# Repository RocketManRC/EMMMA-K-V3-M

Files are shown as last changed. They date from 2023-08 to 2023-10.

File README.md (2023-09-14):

# EMMMA-K-V3

# Introduction
The EMMMA-K is a MIDI controller for electronic music that uses touch pins for note keys and user interface. A motion sensor is used to generate MIDI commands for effects such as pitch bend and mod wheel.

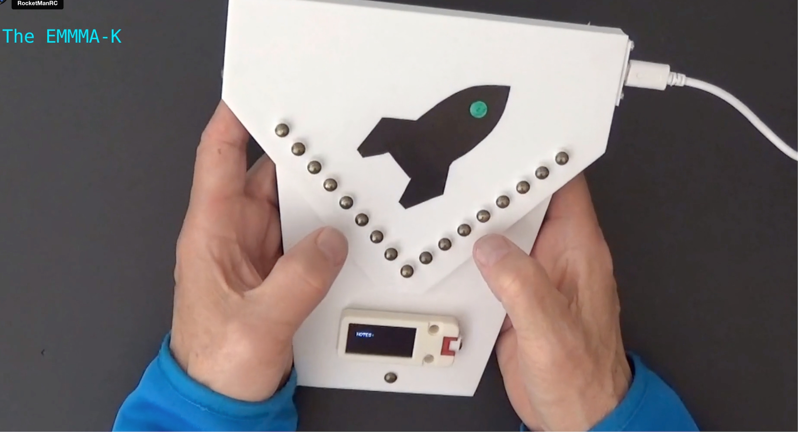
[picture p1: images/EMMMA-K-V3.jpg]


The layout of the touch pins for note keys is modeled after the Kalimba (a.k.a. thumb piano) which is a modernized version of the MBira, an ancient African plucked string instrument.

The history and evolution of the MBira and Kalimba is given on Wikipedia here:

[https://en.wikipedia.org/wiki/Mbira](https://en.wikipedia.org/wiki/Mbira)

A great place to see and hear what the Kalimba is all about is April Yang's YouTube channel:

[https://www.youtube.com/channel/UCV0A2VeScCoxiMhsA2kiIKw](https://www.youtube.com/channel/UCV0A2VeScCoxiMhsA2kiIKw)

In January, 2020 I became interested in making an electronic version of the Kalimba because I wanted a keyboard for electronic music that wasn't piano based and also could be hand-held. In March of that year I started working on a proof-of-concept prototype which I called the EMMMA-K. A write-up of that project is on my website here:

[https://www.rocketmanrc.com/emmma-k.html](https://www.rocketmanrc.com/emmma-k.html)

As crude as that first prototype was it actually performed pretty well and so when the COVID-19 lockdown started I decided to spend the time on a second version that had a better shape and layout and would be easier to build. There is also a write-up of that project here:

[https://www.rocketmanrc.com/emmma-k-v2.html](https://www.rocketmanrc.com/emmma-k-v2.html)

This version supported additional music scales in addition to the Kalimba's C Major scale and a user interface was provided to change scale, key and octave.

Fast forward to October 2022... After working on a number of other unrelated projects I started researching what microcontrollers could be used to replace the TeensyLCs I was using that were no longer available due to the dreaded world-wide semiconductor shortage. The primary requirement was touch pin performance meaning good sensitivity and low latency. I discovered that the new ESP32-S2 and ESP32-S3 from Espressif are excellent for this purpose and so the EMMMA-K-V3 was born.

**Videos:**

[https://vimeo.com/858654116](https://vimeo.com/858654116) Introduction

[https://vimeo.com/858421865](https://vimeo.com/858421865) Overview of Features

[https://vimeo.com/858731197](https://vimeo.com/858731197) Under the Hood

# Features

- Kalimba style keyboard with highly responsive and low latency touch pins.
- USB-C connector for USB MIDI and/or power.
- Wireless MIDI over BLE (Bluetooth Low Energy) or ESP-Now wireless to a USB MIDI hub or a Serial MIDI hub.
- ESP-Now wireless is ultra low latency (approximately 1.5 milliseconds).
- Dedicated option touch pin on the right side to enable tilt sensor for pitch bend and mod wheel (or other CC command).
- Multipurpose option touch pin on the left side for switching between major and minor relative scales, changing to chord mode and disabling the adjacent pin and dissonant note filters.
- User interface with OLED display and dedicated touch pins.
- Change Octave, Key and Scale on the fly or display notes as played.
- Settings mode to enable or disable filters, change MIDI channel, set master volume, set CC for mod wheel and choose wireless mode.

# System Design

This is a dual microcontroller master/slave system with a ESP32-S3 used for the master and a ESP32-S2 (or S3) for the slave. Each microcontroller has 14 touch pins and the ESP32-S3 is required for the master to support wireless over BLE (the ESP32-S2 does not). The microcontrollers exchange pin data via a UART connection with the master polling the slave for synchronous communications. The baud rate is set to 2000000 baud to eliminate any noticable latency.

The motion sensor is a breakout board with a MPU-6050 IMU and is connected to the master via I2C. The board provides three absolute angle measurments (roll, pitch and yaw) using the internal processing of the MPU-6050. The roll axis is used for the mod wheel and the pitch axis is used for pitch bend. The yaw axis is not currently used but could be used for some other purpose.

The use of the motion sensor to generate effects is enabled by touching and holding the option pin on the right hand side of the enclosure. This does not require a note to be played which has the advantage of allowing the EMMMA-K to be used for effects along with another MIDI controller. It also has the advantage that the effects will still be applied to a note with sustain even if the noteoff MIDI command has been issued. When the option pin is touched centre angles are calculated for roll and pitch and then the effects are calculated relative to that those. The logic can be changed so that absolute angles are used which works just as well and is a matter of personal preference. Generation of the effects uses a concept from model aviation called "expo". This means that the change in value of the effects are reduced around around the centre position giving a much smoother response overall.

A OLED display of resolution of 128 by 64 pixels is used for the user interface along with three dedicated touch pins. This display is on a seperate I2C port.

Power for the system is provided by a USB connection to a USB power pack or computer USB port.

To minimize point to point wiring PCBs have been designed to carry both the Master and Slave microcontroller boards.

The microcontroller boards are the ESP32-S3-DevKitC-1 and ESP32-S2-DevKitC-1 from Espressif and are available from all the major component suppliers. Alternatively there are versions of the S3 dev board available from AliExpress.

The code for the slave processor (inspite of what Github says in the repository list and pins) is located here:

[https://github.com/RocketManRC/EMMMA-K-V3-S](https://github.com/RocketManRC/EMMMA-K-V3-S)

The code for the wireless hub is located here:

[https://github.com/RocketManRC/EMMMA-K-V3-W](https://github.com/RocketManRC/EMMMA-K-V3-S)



# Building

I've designed a 3D-printed case that has evolved quite a bit since the very first prototype. I've tried to make it as ergonomic as possible in terms of size and balance and spacing between touch pins. The STL files for 3D printing are here [STL](STL-Files).

It is not necessary to have the 3D-printed case to try out this system as something made of foam board from the Dollar store works just fine.

I do recommend getting the printed circuit boards however as it makes the wiring for the touch pins a lot easier and reproducable although hand wiring will work as well. I had my boards made at JLCPCB. 

The KiCAD 6 design files and the gerbers are here [PCBs](KiCAD).

### Wiring:

| Master MCU | Slave MCU |
| --- | --- |
| GND | GND |
| 38 | TX |
| 39 | RX |

| Master MCU | MPU6050 |
| --- | --- |
| GND | GND |
| 41 | SDA |
| 42 | SCL |
| 3.3V | VCC |

| Master MCU | OLED |
| --- | --- |
| GND | GND |
| 5V | 5V |
| 36 | SCL |
| 35 | SDA |

# Firmware

This is a PlatformIO project using the Arduino Framework. It might be possible to build the firmware using the Arduino IDE however this has not been tested as I don't use the Arduino IDE anymore.

Here is a short YouTube video that shows what is required to build and upload a PlatformIO project [https://www.youtube.com/watch?v=nlE2203Q3XI](https://www.youtube.com/watch?v=nlE2203Q3XI).

### Note: 

There is a quirk with the ESP32-S3 microcontroller that when a project uses USB MIDI the microcontroller must be put in bootloader mode before uploading new firmware otherwise there will be an error. This is not the case if USB MIDI is disabled. In platformio.ini you will see a comment telling how to enable and disable USB MIDI.

# User Guide

# User Interface Photos



### Main Menu:

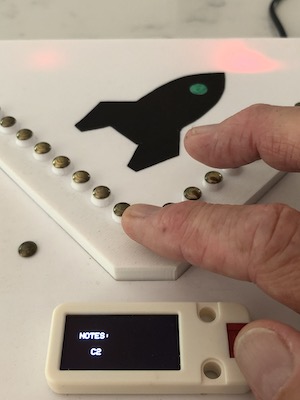
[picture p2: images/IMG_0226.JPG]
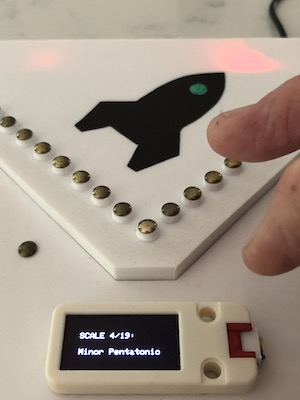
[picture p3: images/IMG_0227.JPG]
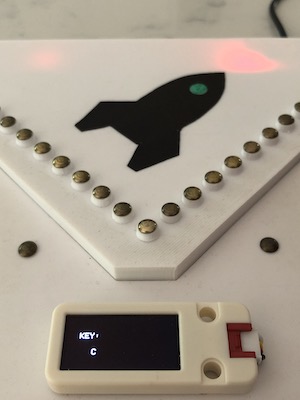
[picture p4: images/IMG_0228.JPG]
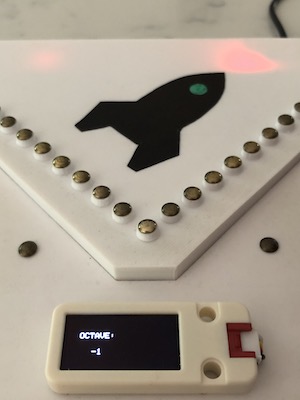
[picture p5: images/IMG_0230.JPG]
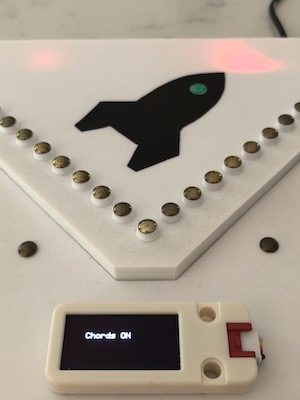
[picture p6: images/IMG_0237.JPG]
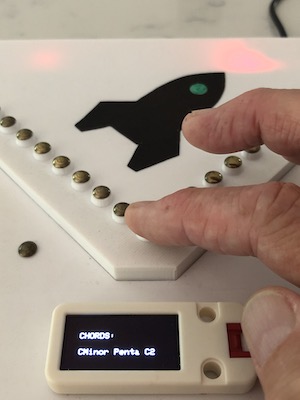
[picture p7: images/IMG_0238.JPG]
      

### Settings:

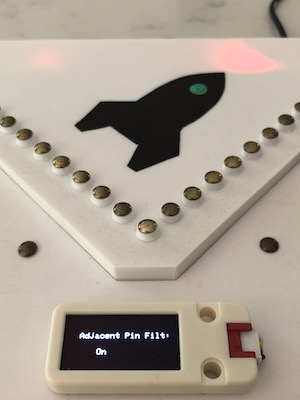
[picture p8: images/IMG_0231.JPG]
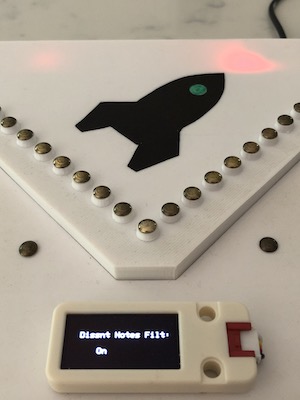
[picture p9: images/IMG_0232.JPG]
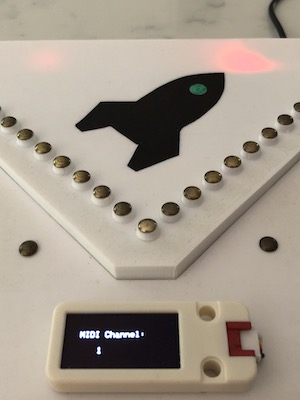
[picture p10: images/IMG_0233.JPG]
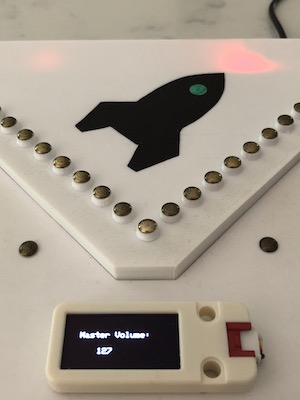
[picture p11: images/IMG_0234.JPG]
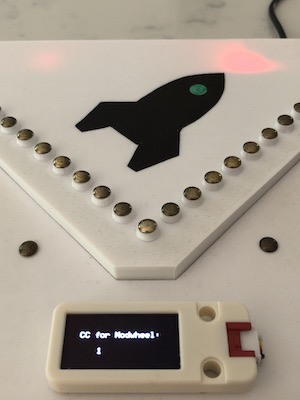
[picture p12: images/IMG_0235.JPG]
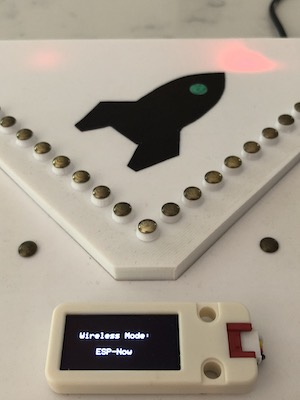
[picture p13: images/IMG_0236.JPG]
     

# Reference Data

ESP32-S2-DevKitC-1: [https://docs.espressif.com/projects/esp-idf/en/latest/esp32s2/hw-reference/esp32s2/user-guide-s2-devkitc-1.html](https://docs.espressif.com/projects/esp-idf/en/latest/esp32s2/hw-reference/esp32s2/user-guide-s2-devkitc-1.html)

ESP32-S3-DevKitC-1: [https://docs.espressif.com/projects/esp-idf/en/latest/esp32s3/hw-reference/esp32s3/user-guide-devkitc-1.html](https://docs.espressif.com/projects/esp-idf/en/latest/esp32s3/hw-reference/esp32s3/user-guide-devkitc-1.html)

ESP32-S3-DevKitC-1 (N8R2 version) from AliExpress: [https://vi.aliexpress.com/item/1005004586894190.html](https://vi.aliexpress.com/item/1005004586894190.html)

USB-C Breakout Board from AliExpress: [https://vi.aliexpress.com/item/1005001337982060.html](https://vi.aliexpress.com/item/1005001337982060.html) Make sure to choose the female connector although having both may come in handy.

Schottky Diode: [https://www.digikey.ca/en/products/detail/panjit-international-inc/SS1040L-R1-00001/14660138](https://www.digikey.ca/en/products/detail/panjit-international-inc/SS1040L-R1-00001/14660138)

Upholstery Nails (for touch pins): [https://www.amazon.ca/Upholstery-Vintage-Furniture-Upholster-Decorative/dp/B08Q7XC9Y1](https://www.amazon.ca/Upholstery-Vintage-Furniture-Upholster-Decorative/dp/B08Q7XC9Y1)

ABS Glue: [https://a.co/d/97ip9cB](https://a.co/d/97ip9cB) I purchased this locally at the hardware store.

Nylon Standoffs and screws: [https://a.co/d/cQluBSF](https://a.co/d/cQluBSF)

M5 Stack OLED Display: [https://vi.aliexpress.com/item/1005003297480376.html](https://vi.aliexpress.com/item/1005003297480376.html) I bought mine from DigiKey for less but at the moment (September 14, 2023) they only have 2 left in stock

MPU-6050 Breakout Board: [https://a.co/d/5xTt3AK](https://a.co/d/5xTt3AK)

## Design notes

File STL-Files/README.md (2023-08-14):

# STL Files for 3D Printing

-  The pieces are printed with ABS both for strength and for ease of gluing the pieces together (other filament types should work just as well except for the gluing).
-  There is a PNG file for each piece to show what it looks like.

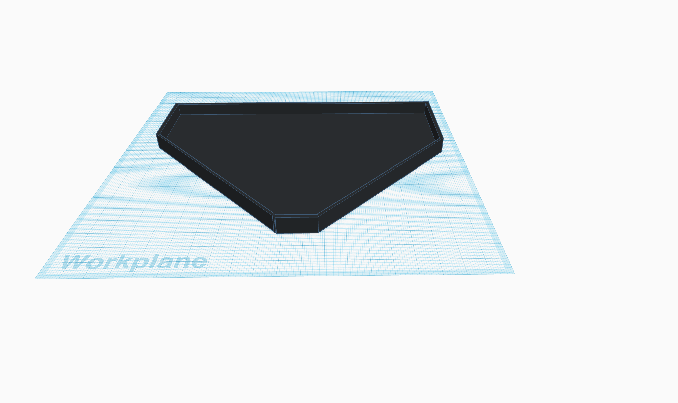
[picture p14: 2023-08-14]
STL-Files/CoverThin-EMMMA-K-v3.2.png

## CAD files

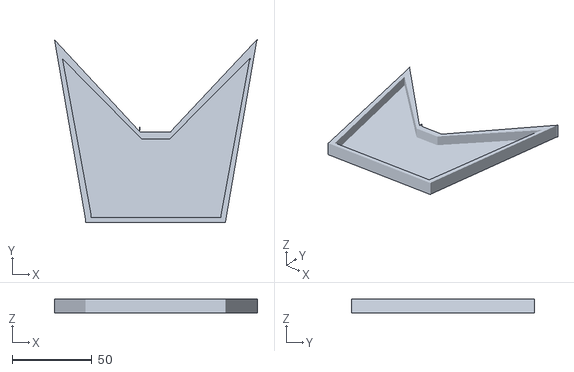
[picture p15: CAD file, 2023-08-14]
STL-Files/CoverThin-LowerPlate-EMMMA-K-v3.2.stl
127.6 x 115.0 x 9.00

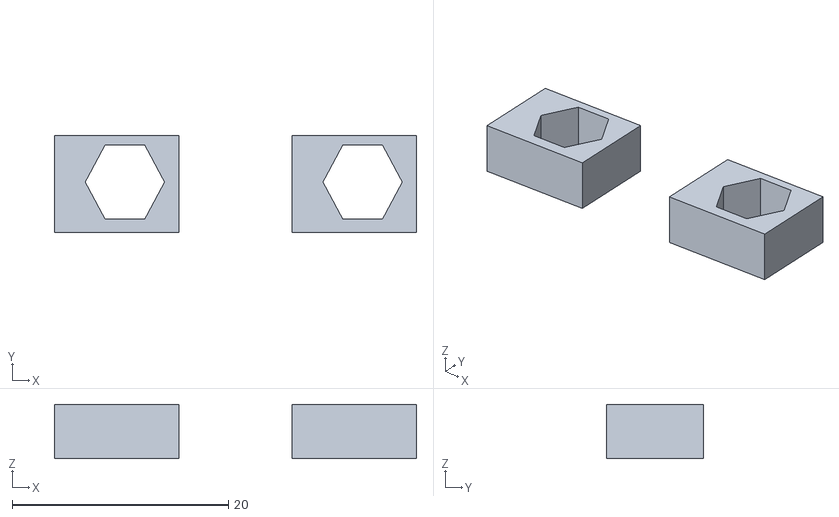
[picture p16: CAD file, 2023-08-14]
STL-Files/Hex-spacer-holder-bottom.stl
33.5 x 9.00 x 5.00

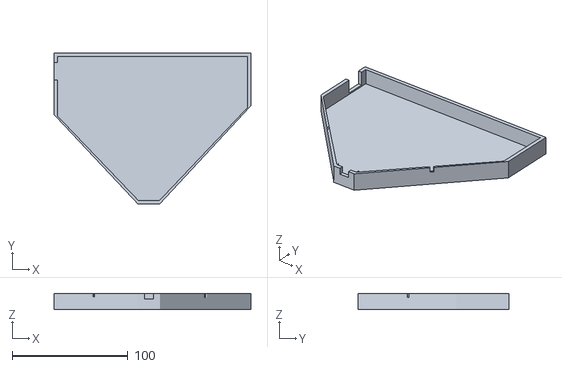
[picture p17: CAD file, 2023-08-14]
STL-Files/EMMMA-K-v3.2.stl
170.0 x 130.0 x 14.0

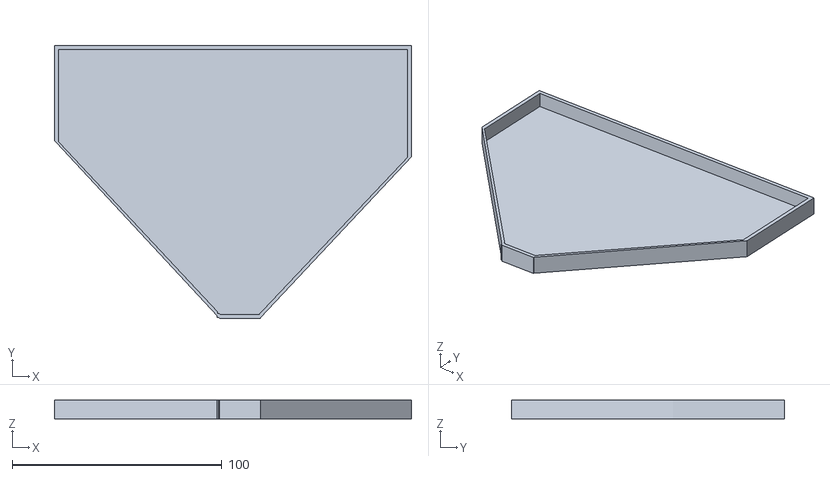
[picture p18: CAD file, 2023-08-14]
STL-Files/CoverThin-EMMMA-K-v3.2.stl
170.0 x 130.0 x 9.00

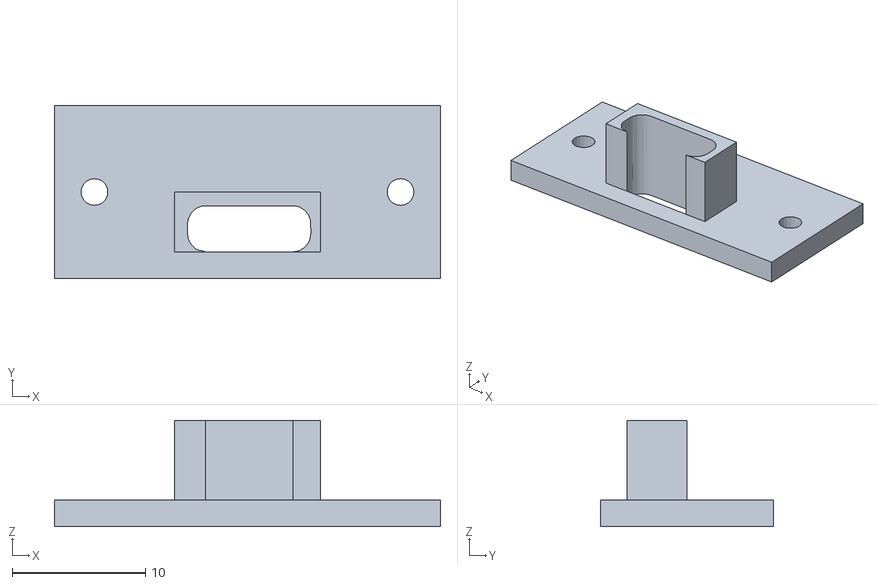
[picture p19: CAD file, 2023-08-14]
STL-Files/USB-C-AdapterPlateEMMMA-K-v3.stl
29.0 x 13.0 x 8.00

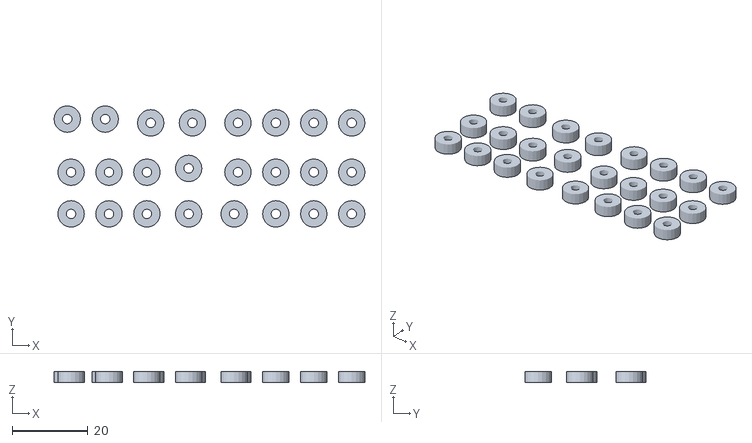
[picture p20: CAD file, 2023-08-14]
STL-Files/EMMMA-K-v3-pin-spacers-24.stl
82.0 x 32.0 x 3.00

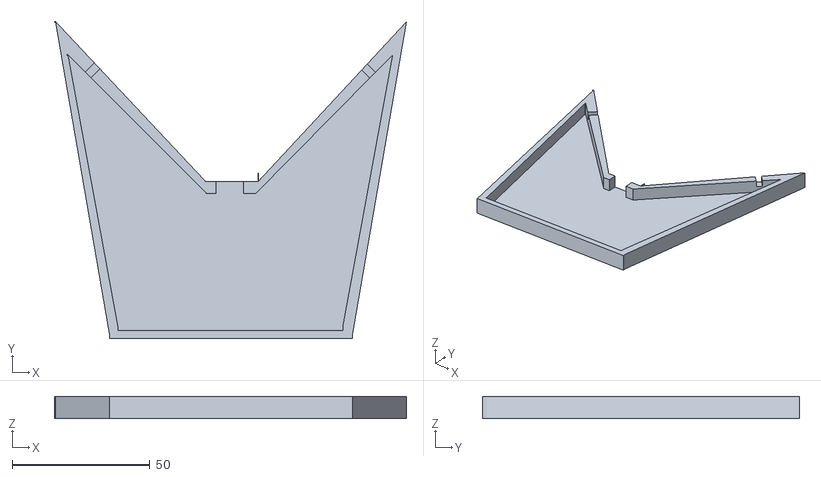
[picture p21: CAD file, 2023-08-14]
STL-Files/LowerPlate-EMMMA-K-v3.2.stl
127.6 x 115.0 x 8.00

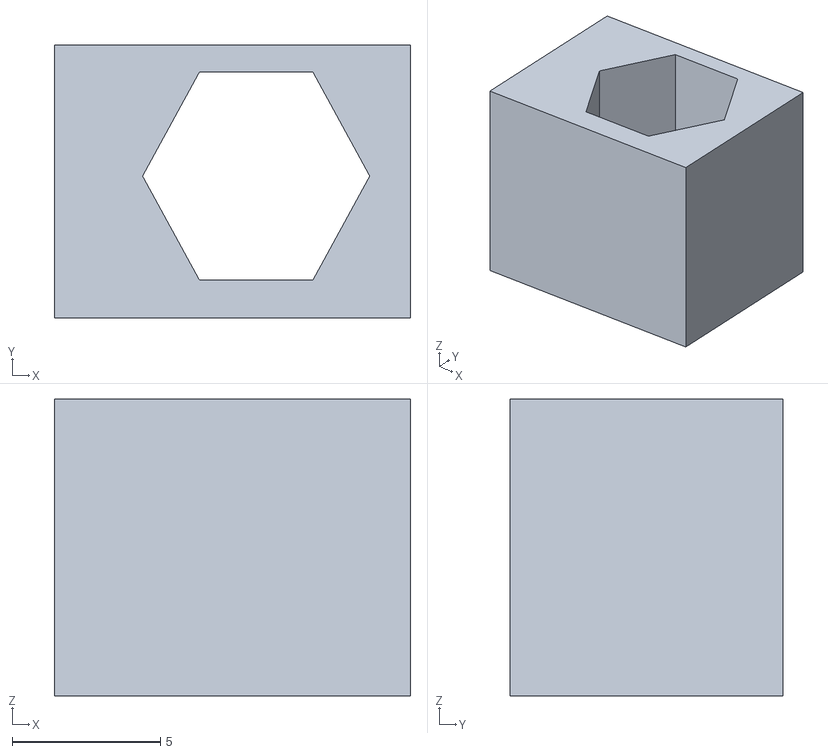
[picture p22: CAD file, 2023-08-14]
STL-Files/Hex-spacer-holder.stl
12.0 x 9.20 x 10.0

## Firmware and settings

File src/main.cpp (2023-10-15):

/* 

This is the source code for the EMMMA-K-v3.2 Master processor (ESP32-S3).

Copyright 2023 RocketManRC

Licensed under the Apache License, Version 2.0 (the "License");
you may not use this file except in compliance with the License.
You may obtain a copy of the License at

   http://www.apache.org/licenses/LICENSE-2.0

Unless required by applicable law or agreed to in writing, software
distributed under the License is distributed on an "AS IS" BASIS,
WITHOUT WARRANTIES OR CONDITIONS OF ANY KIND, either express or implied.
See the License for the specific language governing permissions and
limitations under the License.

If you use this code for any purpose please make sure that you
are not infringing on any third party's intellectual property rights.

The following opensource libraries are used by this software and are much appreciated:

Adafruit BusIO - MIT License
Adafruit GFX Library - BSD License
Adafruit NeoPixel - GLPL License
Adafruit SH110X - BSD License
Adafruit SPI Flash - MIT License
Adafruit TinyUSB Library - MIT License
ArduinoBLE - GLPL License
ArduinoJson - MIT License
BLE-MIDI - MIT License
I2Cdevlib - MIT License
MIDI Library - MIT License
NimBLE-Arduino - Apache License
SdFat - Adafruit Fork - MIT License

To support USB MIDI the following library is required
    MIDI Library by Forty Seven Effects
    https://github.com/FortySevenEffects/arduino_midi_library
  
 There is a bug in thislibrary for MIDI pitch bend where it will only bend up. Need to 
 change line 343 in MIDI.hpp to:

 const int value = int(fabs(inPitchValue) * double(scale));

 The file is in $PROJECT_DIR/.pio/ESP32-S3-DevKitC/MIDI Library/src

 A patch to fix this should be applied automatically via patchfile.py
 which is executed by PlatformIO prior to building.

*/

#include <Arduino.h>
#include <LittleFS.h>
#include "driver/touch_pad.h"
#include <BLEMIDI_Transport.h>
#include <hardware/BLEMIDI_ESP32_NimBLE.h>
#include <Adafruit_TinyUSB.h>
#include <MIDI.h>
#include <WiFi.h>
#include <esp_now.h>
#include <Adafruit_NeoPixel.h>
#include <Wire.h>
#include <Adafruit_GFX.h>
#include <Adafruit_SH110X.h>
#include <ArduinoJson.h>  

// forward references
void handleChangeRequest(uint8_t type, uint8_t data1, uint8_t data2);
void MPU6050Setup();
void MPU6050Loop();
void displayRefresh(); // Should displayMode() be used instead???
void displayMode();

// Configuration Default Values
// To change the config update one or more of these values and rebuild.
String configInit = "3.14159265359"; // if this is changed config will be initialized (default 3.14159265359)
bool useBluetooth = false;
int scaleIndex = 3; // default is minor pentatonic
uint8_t midiChannel = 1;
int masterVolume = 127; 
bool adjacentPinsFilter = true;
bool dissonantNotesFilter = true;
uint8_t ccForModwheel = 1;
String broadcastAddressMidiHub = "123456";

bool optionsMode = true; // if true UI changes options (scale, key, etc), else UI changes config
bool wirelessChanged = false; // this will be set when the wireless mode changed causing a restart
bool enableAdjacentPins = false;
bool enableDissonantNotes = false;

float ypr[3];  // [yaw, pitch, roll]   yaw/pitch/roll container and gravity vector

#define SCREEN_WIDTH 64  // OLED display width, in pixels
#define SCREEN_HEIGHT 128 // OLED display height, in pixels
#define OLED_RESET -1     // can set an oled reset pin if desired
Adafruit_SH1107 display = Adafruit_SH1107(SCREEN_WIDTH, SCREEN_HEIGHT, &Wire, OLED_RESET, 1000000, 100000);

// ************ The following define should normally be 1 for USB MIDI. Also must set the compile flag in platformio.ini ************
#define USEMIDI 0 // set to 0 to force remote via wireless (ESP-Now or BLE)

#define SERIALSLAVE Serial1

uint8_t broadcastAddressRgbMatrix[] = {0x4C, 0x75, 0x25, 0xA6, 0xD6, 0x34};   // Experiment with the Atom Lite and RGB LED matrix

bool binding = false; // this will be set to true if middle touch pin pressed during startup

// I wanted to use the RGB LED to show note colours using Scriabin's Colour Sequence 
// but the Neopixel update is too slow and it adds random latency into the note generation.
// For now I just use the LED for status and error indications:
// GREEN - USB MIDI has successfully started.
// RED - ESP-Now fails initialization or packet failed to be delivered.
// BLUE - Using ESP-Now.

uint32_t espNowMicrosAtSend = 0;
uint32_t espNowReturnTime = 0;  // this will hold the return time of Esp_now in microseconds
uint8_t espNowDeliveryStatus = 0xFF;

bool bluetoothConnected = false; // will be set when bluetooth connected

#define RGBLED 0 // set to 1 to show note colours 

Adafruit_NeoPixel pixels(1, 48, NEO_GRB + NEO_KHZ800); // ESP32-S3 DevKitC

const int MPU_addr = 0x68; // for the 6050

uint32_t scriabinColourSequence[12] = {0xFF0000, 0xCD9AFF, 0xFFFF00, 0x656599, 0xE3FBFF, 0xAC1C02, 0x00CCFF,
  0xFF6501, 0xFF00FF, 0x33CC33, 0x8C8A8C, 0x0000FE};

void handleNoteOn(byte channel, byte pitch, byte velocity);
void handleNoteOff(byte channel, byte pitch, byte velocity);

// USB MIDI object
Adafruit_USBD_MIDI usb_midi;

// BLE MIDI
BLEMIDI_CREATE_INSTANCE("EMMMA-K", MIDI)    

// Create a new instance of the Arduino MIDI Library,
// and attach usb_midi as the transport.
// Note that USB MIDI won't be enabled unless the proper
// compile options are set. See the comments in platformio.ini.
MIDI_CREATE_INSTANCE(Adafruit_USBD_MIDI, usb_midi, USBMIDI);

bool midiOn = false;

int key  = 0;
int octave = -1;
int scale = 0;

const uint8_t numPins = 14;  // The MCU has 14 touch pins
const uint8_t notePins = 9;  // and the master has 9 note pins

static const touch_pad_t pins[numPins] = 
{
    TOUCH_PAD_NUM4,
    TOUCH_PAD_NUM5,
    TOUCH_PAD_NUM6,
    TOUCH_PAD_NUM9,
    TOUCH_PAD_NUM10,
    TOUCH_PAD_NUM11,
    TOUCH_PAD_NUM12,
    TOUCH_PAD_NUM13,
    TOUCH_PAD_NUM14,
    TOUCH_PAD_NUM7,
    TOUCH_PAD_NUM8,
    TOUCH_PAD_NUM3,
    TOUCH_PAD_NUM1,
    TOUCH_PAD_NUM2
};

static uint32_t benchmark[numPins]; // to store the initial touch values of the pins

// notes (17 total) and scales (choose one)
uint8_t majorscale[] = {2, 2, 1, 2, 2, 2, 1}; // case 1
uint8_t minorscale[] = {2, 1, 2, 2, 1, 2, 2}; // case 2
uint8_t pentascale[] = {2, 2, 3, 2, 3}; // case 3
uint8_t minorpentascale[] = {3, 2, 2, 3, 2};  // case 4
uint8_t minorbluesscale[] = {3, 2, 1, 1, 3, 2}; // case 5

uint8_t majorbluesscale[] = {2, 1, 1, 3, 2, 3}; // case 6
uint8_t minorharmonic[] = {2, 1, 2, 2, 1, 3, 1};  // case 7
uint8_t minormelodic[] = {2, 1, 2, 2, 2, 2, 1}; // case 8
uint8_t minorpo33[] = {2, 1, 2, 2, 1, 2, 1, 1}; // case 9

uint8_t dorian[] = {2, 1, 2, 2, 2, 1, 2}; // case 10
uint8_t phrygian[] = {1, 2, 2, 2, 1, 2, 2}; // case 11
uint8_t lydian[] = {2, 2, 2, 1, 2, 2, 1};  // case 12
uint8_t mixolydian[] = {2, 2, 1, 2, 2, 1, 2}; // case 13
uint8_t aeolian[] = {2, 1, 2, 2, 1, 2, 2};  // case 14
uint8_t locrian[] = {1, 2, 2, 1, 2, 2, 2};  // case 15
uint8_t lydiandomiant[] = {2, 2, 2, 1, 2, 1, 2};  // case 16
uint8_t superlocrian[] = {1, 2, 1, 2, 2, 2, 2}; // case 17

uint8_t wholehalfdiminished[] = {2, 1, 2, 1, 2, 1, 2, 1}; // case 18
uint8_t halfwholediminished[] = {1, 2, 1, 2, 1, 2, 1, 2}; // case 19
uint8_t chromatic[] = {1, 1, 1, 1, 1, 1, 1, 1, 1, 1, 1}; // case 20

const int totalNotePins = 17; // 17 note pins on the keyboard itself 
const int totalNotes = 24;    // 17 notes plus room for chord notes above the last one including inversions

bool notePinsOn[totalNotePins] = {false};
uint8_t midiValues[totalNotes]; 

#define OCTAVE 12
#define KEY G - OCTAVE // choose desired key and octave offset here

bool option1 = false; // right top (on PCB) option pin (pitchbend)
bool option2 = false; // right middle (on PCB) option pin (mode value up)
bool option3 = false; // right bottom (on PCB) option pin (mode value down)
bool option4 = false; // left top (on PCB) option pin (3 functions: change relative scale, enable/disable chords, modwheel)
bool option5 = false; // left middle (on PCB) option pin (not used)
bool option6 = false; // left bottom (on PCB) option pin (2 functions: change mode and change config)

void displayValue(String title, String value);
String keyNames[] = {"C", "C#", "D", "D#", "E", "F", "F#", "G", "G#", "A", "A#", "B"};

String mode = "Scale";
String scales[] = {"Major", "Minor", "Major Pentatonic", "Minor Pentatonic", 
  "Major Blues", "Minor Blues", "Minor Harmonic", "Minor Melodic", "Minor PO-33", "Dorian",
  "Phrygian", "Lydian", "Mixolydian", "Aeolian", "Locrian",
  "Lydian Dominished", "Super Locrian", "Whole Half Dim", "Half Whole Dim", "Chromatic"};

int scaleCount = sizeof(scales)/sizeof(scales[0]); 

bool playChords = false;

bool notePlayedWhileOption4Touched = false;

//String config = "Adjacent Key Filt";
uint8_t config = 0;
String configs[] = {"Adjacent Pin Filt", "Dissnt Notes Filt", "MIDI Channel", "Master Volume",
  "CC for Modwheel", "Wireless Mode", "Save & Exit", "Exit NO Save"};
uint8_t numberOfConfigItems = sizeof(configs)/sizeof(configs[0]);
void displayAdjacentPinFilt();
void displayDissonantNotesFilt();
void displayMidiChannel();
void displayMasterVolume();
void displayCcForModwheel();
void displayWirelessMode();
void displaySaveExitPrompt();
void displayExitNoSavePrompt();
void (*configDisplayFunctions[])() = {displayAdjacentPinFilt, displayDissonantNotesFilt, displayMidiChannel, displayMasterVolume,
  displayCcForModwheel, displayWirelessMode, displaySaveExitPrompt, displayExitNoSavePrompt};
void changeAdjacentPinFilt(bool up);
void changeDissonantNotesFilt(bool up);
void changeMidiChannel(bool up);
void changeMasterVolume(bool up);
void changeCcForModwheel(bool up);
void changeWirelessMode(bool up);
void saveExitConfig(bool up);
void exitNoSaveConfig(bool up);
void saveConfig();
void (*configChangeFunctions[])(bool) = {changeAdjacentPinFilt, changeDissonantNotesFilt, changeMidiChannel, changeMasterVolume,
  changeCcForModwheel, changeWirelessMode, saveExitConfig, exitNoSaveConfig};


void displayValue(String title, String value)
{
  display.clearDisplay();
  display.setCursor(15,20);
  display.print(title + ":");
  if(value.length() > 15)
    display.setCursor(15, 40);
  else
    display.setCursor(30, 40);
  display.print(value);
  display.display();
}

void displayScale()     
{
  displayValue(String("SCALE") + " " + String(scaleIndex + 1) + "/" + String(scaleCount), String(scales[scaleIndex]));
}

void displayKey()
{
  displayValue(String("KEY"), keyNames[key]);
}

void displayOctave()
{
  displayValue(String("OCTAVE"), String(octave));
}

void displayNotes(bool init)
{
  if(init)
  {
    displayValue(String("NOTES"), "none");
  }
  else if(mode == "Note")
  {
    String noteNames = "";

    for(int i = 0; i < totalNotePins; i++)
    {
      if(notePinsOn[i])
      {
        uint8_t midiValue = midiValues[i] + octave * 12 + key;
        uint8_t idx = midiValue % 60;
        noteNames += String(keyNames[idx % 12]) + String(midiValue/12 - 2);

        if(i < totalNotePins - 1)
          noteNames += " ";
      }
    }

    if(noteNames != "") // Only display elapsed time if notes to display
    {
      if(espNowReturnTime) // are we using wireless (espNowReturnTime is nonzero)?
      {
        if(espNowReturnTime == 0xFFFFFFFF)
          noteNames += " Fail!";
        else
          noteNames += " " + String(espNowReturnTime);
      }
    }

    displayValue(String("NOTES"), noteNames);
    //Serial.println(espNowReturnTime);
  } 
}

void displayAdjacentPinFilt()     
{
  if(adjacentPinsFilter)
    displayValue(String(configs[config]), String(" On"));
  else
    displayValue(String(configs[config]), String(" Off"));
}

void displayDissonantNotesFilt()     
{
  if(dissonantNotesFilter)
    displayValue(String(configs[config]), String(" On"));
  else
    displayValue(String(configs[config]), String(" Off"));
}

void displayMidiChannel()     
{
  displayValue(String(configs[config]), String(" ") + String(midiChannel));
}

void displayMasterVolume()     
{
  displayValue(String(configs[config]), String(" ") + String(masterVolume));
}

void displayCcForModwheel()     
{
  displayValue(String(configs[config]), String(" ") + String(ccForModwheel));
}

void displayWirelessMode()     
{
  if(useBluetooth)
    displayValue(String(configs[config]), String(" ") + "BLE");
  else
    displayValue(String(configs[config]), String(" ") + "ESP-Now");
}

void displaySaveExitPrompt()
{
  displayValue(String("Save & Exit"), String("->"));
}  

void displayExitNoSavePrompt()
{
  displayValue(String("Exit NO Save"), String("->"));
}  

bool chordSupported()
{
  String s = String(scales[scaleIndex]);

  bool result = (s == "Major") || (s == "Minor") || (s == "Major Pentatonic") ||
    (s == "Minor Pentatonic") || (s == "Minor Blues");

  return result;
}
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
void loop() 
{
  uint32_t touch_value;

  if(SERIALSLAVE.availableForWrite())
    SERIALSLAVE.write(0xA5);

    // read and process the right option pins

    touch_pad_read_raw_data(pins[9], &touch_value);   // right top (on PCB) option pin
    if(touch_value > benchmark[9] + (0.3 * benchmark[9]))
      option1 = true;
    else if(touch_value < benchmark[9] + (0.2 * benchmark[9]))
      option1 = false;

    touch_pad_read_raw_data(pins[10], &touch_value);   // right middle (on PCB) option pin
    if(touch_value > benchmark[10] + (0.3 * benchmark[10]))
      option2 = true;
    else if(touch_value < benchmark[10] + (0.2 * benchmark[10]))
      option2 = false;

    touch_pad_read_raw_data(pins[11], &touch_value);   // right bottom (on PCB) option pin
    if(touch_value > benchmark[11] + (0.3 * benchmark[11]))
      option3 = true;
    else if(touch_value < benchmark[11] + (0.2 * benchmark[11]))
      option3 = false;

  // The master has 9 note pins which correspond to the even midiValues[]

  for(int i = 0; i < notePins; i++)
  {
    uint8_t idx = (i * 2); 
    uint8_t ofs = key + octave * 12;

    touch_pad_read_raw_data(pins[i], &touch_value);

    if(touch_value > benchmark[i] + (0.3 * benchmark[i]) && !adjacentPinOn(i)  && !dissonantNoteOn(i * 2))
    {
      if(dissonantNoteOn(i * 2))
      {
        //Serial.println("Dissonant note is already on!");
      }

      if(!notePinsOn[i * 2])
      {
        notePinsOn[i * 2] = true;

        if(option4)
        {
          notePlayedWhileOption4Touched = true; 
        }

        if(playChords)
        {
          sendChordOn(idx, ofs);
        }
        else
        {
          if(midiOn)
          {
            USBMIDI.sendNoteOn(midiValues[idx] + ofs, masterVolume, midiChannel);
          }
          else
          {
            uint8_t msgNote[] = {(uint8_t)(midiValues[i * 2] + key + octave * 12), 1, (uint8_t)masterVolume, midiChannel}; 

            espNowMicrosAtSend = micros();
            esp_err_t outcome = wirelessSend((uint8_t *) &msgNote, sizeof(msgNote));  
            
            if(outcome)
            {
              //Serial.println("Error sending master noteOn");
              pixels.setPixelColor(0, 0x00FFFF); // set LED to yellow
              pixels.show(); 
            }
          }
        }

      if(playChords  && chordSupported())
        displayChords(false);
      else
        displayNotes(false);
        
        showNoteColour(midiValues[i * 2]);
      }
    }
    else if(touch_value < benchmark[i] + (0.2 * benchmark[i]))
    {
      if(notePinsOn[i * 2])
      {
        notePinsOn[i * 2] = false;

        if(playChords)
        {
          sendChordOff(idx, ofs); // chords are handled seperately
        }
        else 
        {
          if(midiOn)
          {
            USBMIDI.sendNoteOff(midiValues[idx] + ofs, 0, 1);
          }
          else
          {
            uint8_t msgNote[] = {(uint8_t)(midiValues[i * 2] + key + octave * 12), 0, (uint8_t)0, midiChannel}; 

            espNowMicrosAtSend = micros();
            esp_err_t outcome = wirelessSend((uint8_t *) &msgNote, sizeof(msgNote));  

            if(outcome)
            {
              //Serial.println("Error sending master noteOff");
              pixels.setPixelColor(0, 0x00FFFF); // set LED to yellow
              pixels.show(); 
            }
          }
        }
        
      if(playChords && chordSupported())
        displayChords(false);
      else
        displayNotes(false);        
      }
    }
  }
   
  float ax;
  float ay; 
  float az;

  static uint32_t t0 = millis();

  static uint32_t lastOption4millis = t0;
  static bool option4Touched = false;

  // This is the pitchbend and modwheel stuff. Only do every 25ms
  if(millis() - t0 > 25)
  {
    t0 = millis();

    // The MPU6050 processing. Pitch is used for pitch bend and roll for modwheel

    MPU6050Loop();

    messageUpdate(false); // for pop-up message timing

    processPitchBend();

    processModwheel();
  }

  // Read two bytes from the slave asynchronously. The first byte has the MSB set and
  // each byte has data for 7 pins. Only 8 pins are note pins.
  if(SERIALSLAVE.available())
  {
    uint8_t c;
    static uint8_t c1 = 0;
    static uint8_t lastc = 0;
      
    SERIALSLAVE.read(&c, 1);

    if(c & 0x80) // is it the first byte?
    {
      c1 = c; // just save it
      if(c != lastc)
      {
        lastc = c;
        //Serial.print(c, 16);
        //Serial.print(' ');
      }
    }
    else 
    {
      // second byte received
      // first process the first byte
      int i;

      for(i = 0; i < 7; i++)
      {
        bool touched = c1 & (0x40 >> i);

        processRemoteNotes(touched, i);
      }

      i = 7;
      bool touched = c & 0x01; // now look at the note bit in the second byte

      option4 = c & 0x10;

      if(option4)
      {
        if(!option4Touched)
        {
          // Here if touched but wasn't last time
          option4Touched = true;
          lastOption4millis = millis();
        }
      }
      else
      {
        // Here if untouched but it was last time
        if(option4Touched)
        {
          option4Touched = false;

          if(millis() - lastOption4millis < 500)
          {
            Serial.println("Toggle relative major/minor");
            bool success = toggleRelativeMajorMinor();
            String msg;
            if(success)
              msg = "To " + scales[scaleIndex];
            else
              msg = "Scale not supported  or note on";

            displayMessage(msg);
          }
          else
          {
            if(!notePlayedWhileOption4Touched)
            {
              Serial.println("Toggle chords on/off"); 
              if(playChords)
                displayMessage("  Chords OFF");
              else
                displayMessage("  Chords ON");
              playChords = !playChords;
            }
            else
              notePlayedWhileOption4Touched = false;
          }
        }
      }

      option5 = c & 0x80;
      option6 = c & 0x04;

      processRemoteNotes(touched, i);

      static bool lastOption2 = false;
      static bool lastOption3 = false;
      static bool lastOption6 = false;

      if(option2 && !lastOption2 && allNotesOff())
      {
        //Serial.println(optionsMode);
        if(optionsMode)
        {
          if(mode == "Scale")
          {
            changeScale(true);
            displayScale();
          }
          else if(mode == "Key")
          {
            changeKey(true);
            displayKey();
          }
          else if(mode == "Octave")
          {
            changeOctave(true);
            displayOctave();
          }
        }
        else
        {
          // In config mode now
          (*configChangeFunctions[config])(true);

          if(!optionsMode)  // Note that exit will take us out of config mode so in that case don't displayConfig()
            displayConfig();
        }
      }
      
      lastOption2 = option2;

      if(option3 && !lastOption3 && allNotesOff())
      {
        if(optionsMode)
        {
          if(mode == "Scale")
          {
            changeScale(false);
            displayScale();
          }
          else if(mode == "Key")
          {
            changeKey(false);
            displayKey();
          }
          else if(mode == "Octave")
          {
            changeOctave(false);
            displayOctave();
          }
        }
        else
        {
          // In config mode now
          //Serial.println("config mode");
          (*configChangeFunctions[config])(false);

          if(!optionsMode)  // Note that exit will take us out of config mode so in that case don't displayConfig()
            displayConfig();
        }
      }

      lastOption3 = option3;

      // Handle the adjacentPins and dissonantNotes filters
      if(playChords)
      {
        // Force the filters on if we are playing chords
        enableAdjacentPins = false;
        enableDissonantNotes = false;
      }
      else
      {
        // If option4 ignore both filters
        if(option4)
        {
          // Ignore the filters if option4 set
          enableAdjacentPins = true;
          enableDissonantNotes = true;
        }
        else
        {
          // set the enables according to the filters
          //Serial.printf("%d ", adjacentPinsFilter);
          if(adjacentPinsFilter)
            enableAdjacentPins = false;
          else
            enableAdjacentPins = true;

          if(dissonantNotesFilter)
            enableDissonantNotes = false;
          else
            enableDissonantNotes = true;
        }
      }
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

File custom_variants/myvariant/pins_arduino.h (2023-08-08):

#ifndef Pins_Arduino_h
#define Pins_Arduino_h

#include <stdint.h>


#define USB_VID            0x239A
#define USB_PID            0x80EB
#define USB_MANUFACTURER   "Adafruit"
//#define USB_PRODUCT        "ESP32S2"
#define USB_SERIAL         "" // Empty string for MAC adddress


#define EXTERNAL_NUM_INTERRUPTS 46
#define NUM_DIGITAL_PINS        48
#define NUM_ANALOG_INPUTS       20

#define analogInputToDigitalPin(p)  (((p)<20)?(analogChannelToDigitalPin(p)):-1)
#define digitalPinToInterrupt(p)    (((p)<48)?(p):-1)
#define digitalPinHasPWM(p)         (p < 46)

#define LED_BUILTIN     13

#define PIN_NEOPIXEL        33
#define NEOPIXEL_NUM        1     // number of neopixels
#define NEOPIXEL_POWER      21    // power pin
#define NEOPIXEL_POWER_ON   HIGH  // power pin state when on
#define I2C_POWER           7     // I2C power pin
#define PIN_I2C_POWER       7     // I2C power pin

static const uint8_t SDA = 3;
static const uint8_t SCL = 4;

static const uint8_t SS    = 42;
static const uint8_t MOSI  = 35;
static const uint8_t SCK   = 36;
static const uint8_t MISO  = 37;

static const uint8_t A0 = 18;
static const uint8_t A1 = 17;
static const uint8_t A2 = 16;
static const uint8_t A3 = 15;
static const uint8_t A4 = 14;
static const uint8_t A5 = 8;


static const uint8_t TX = 39;
static const uint8_t RX = 38;
#define TX1 TX
#define RX1 RX

static const uint8_t T5 = 5;
static const uint8_t T6 = 6;
static const uint8_t T8 = 8;
static const uint8_t T9 = 9;
static const uint8_t T10 = 10;
static const uint8_t T11 = 11;
static const uint8_t T12 = 12;
static const uint8_t T13 = 13;
static const uint8_t T14 = 14;

static const uint8_t DAC1 = 17;
static const uint8_t DAC2 = 18;

#endif /* Pins_Arduino_h */

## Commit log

2023-08-14 Added patchfile.py to patch the MIDI LIbrary to fix pitch bend and also updated the readme
    [main.cpp]
2023-08-14 Update readme plus add STL and PCB files
    [CoverThin-EMMMA-K-v3.2.stl, CoverThin-LowerPlate-EMMMA-K-v3.2.stl, EMMMA-K-v3-pin-spacers-24.stl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]
2023-09-13 Add PCB files and major cleanup of main.cpp
    [EMMMA-K-v3-wiring.kicad_pcb, EMMMA-K-v3-wiring.kicad_sch]
2023-09-14 Update README.md
    Added tables for wiring components together
